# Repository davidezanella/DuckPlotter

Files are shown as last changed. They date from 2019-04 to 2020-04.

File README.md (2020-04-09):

# DuckPlotter

Arduino plotter made with a 3d printer capable to draw G-Code on paper.

Image of the Duckplotter

Video demo of the DuckPlotter in action:

Video demo of the DuckPlotter in action (https://www.youtube.com/watch?v=VcAsxya50rk)

## How to use DuckPlotter

### Configure the system

* Create the physical structure of the DuckPlotter
* Send code to Arduino
* Install all python requirements:

    go into `computer_code` folder and run

    `pip install -r requirements.txt`

### Generate the Gcode file from an image

#### First solution

* Download and install the program [`Image to gcode - DP`](https://github.com/davidezanella/image-to-gcode-DP) created ad hoc for the DuckPlotter.

#### Second solution

* Download and install the [Inkscape](https://inkscape.org) program and its [Laser Tool Plug-In](http://jtechphotonics.com/?page_id=2012)
* Open your image with Inkscape
* Convert the image to a Path image using the grey scale option
* Ungroup the layers of the image
* Choose the best layer and fix it removing or adding pixels

    If you need help doing these steps follow [this video](https://www.youtube.com/watch?v=U248SJcxRWA).

* Finally export Gcode from your image using the "Extensions" tab and selecting the option "Generate Gcode"

### Start the plotting process

* Execute the duckPlotter program:

    ```
    usage: duckPlotter.py [-h] [--continue PREV_FILE_NAME] file_name serial_port

    DuckPlotter pc program. Send g-code instructions to Arduino.

    positional arguments:
    file_name                       g-code file to plot
    serial_port                     serial port of Arduino

    optional arguments:
    -h, --help                      show this help message and exit
    --continue PREV_FILE_NAME       previous g-code file

    ```

    Example of usage:

    `python3 duckPlotter.py my-gcode-file.gcode /dev/ttyACM0`

    The `--continue` option allow to continue plotting without resetting to the initial position. It needs to know the previous file.

* You can split a gcode file in more files in order to avoid overheatings:

    `python gcodeSplitter.py gcode-file [max-lines]`

    The `max-lines` option allow to split the gcode file every `max-lines` lines. (Default value: 2500)

    All required gcode files will be generated. They have to be executed in order, with the `--continue` option specifying the previous g-code file.

## Used libraries
* [ArduinoJson](https://arduinojson.org)
* [Servo by Michael Margolis, Arduino](https://platformio.org/lib/show/883/Servo)

## Used hardware
* Arduino Mega 2560
* RAMPS 1.4 (RepRap Arduino MEGA Pololu Shield)

## Authors
- [Davide Dorigoni](https://github.com/DavDori)
- [Davide Zanella](https://github.com/davidezanella)

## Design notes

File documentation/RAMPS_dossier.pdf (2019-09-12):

# RAMPS 1.4 Assembly Guide

# 3D Printer Czar

## Version 1

## Table of Content

## Getting to know RAMPS 1.4 ---------------------------------------------------3

## Insert jumpers to RAMPS 1.4---------------------------------------------------4

## Connect the boards---------------------------------------------------------------4

## Crimp Connectors-----------------------------------------------------------------5

## Connect the Power Supply------------------------------------------------------6

## Connect the Rest------------------------------------------------------------------7

## Getting to know RAMPS 1.4

RAMPS 1.4 is probably the most widely used electronics for RepRap machines as of March 2014. It consists of a RAMPS 1.4 shield, an Arduino Mega 2560 board (or a clone), and a max of five Pololu Stepper drivers. It can control up to 5 stepper motors with 1/16 stepping precision and interface with a hotend, a heatbed, a fan (or a second hotend), a LCD controller, a 12V (or 24V with appropriate modification) power supply, up to three thermistors, and up to six end stoppers.

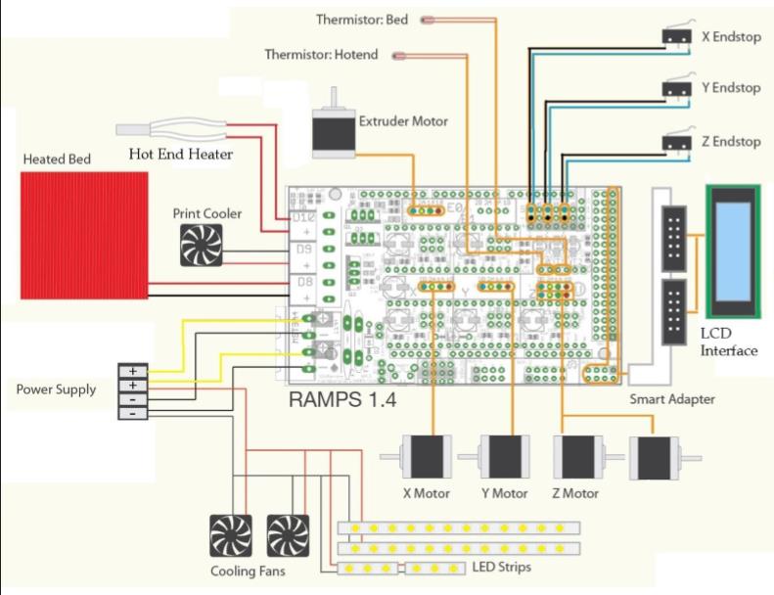
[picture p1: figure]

RAMPS 1.4 Schematic, taken from www.makerfarm.com

## 1. Insert jumpers to RAMPS 1.4

The jumpers (in the plastic bag below) control the precision of the motor movement. To have the most precise stepping (1/16 micro stepping), insert three jumpers to each of the areas outlined below：

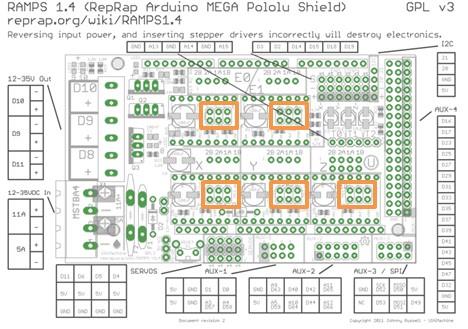
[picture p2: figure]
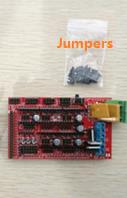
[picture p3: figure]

Install all jumpers to the orange area to ensure the most precise stepping

If you would like to learn about other modes of stepping (full stepping, half stepping, 1/8 stepping, etc.), please refer to this article: http://www.nmbtc.com/step-motors/engineering/full-half-and-microstepping.html. (http://www.nmbtc.com/step-motors/engineering/full-half-and-microstepping.html) These modes are not suitable for 3D printer motion control, but could be useful for other projects.

## 2. Connect the Boards

Stack the RAMPS 1.4 shield on top of the Arduino Mega 2560 board. Make sure the orientation is correct as shown above. The Mega 2560 board’s USB side is directly under RAMPS 1.4 shied’s “D8 D9 D10” area.

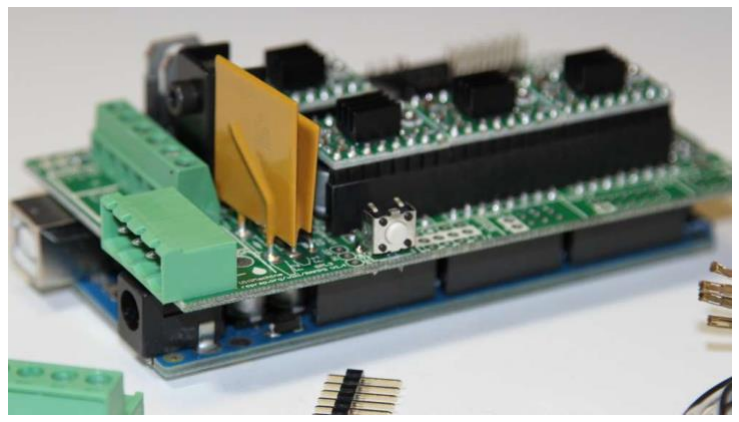
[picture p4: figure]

Stack up the RAMPS 1.4 shield on top of Mega 2560 Board

Next stack the Pololu steppers on top of the RAMPS 1.4 shield. MAKE SURE THE ORIENTATION IS CORRECT AS SHOWN BELOW! The potential meter (outlined in red on the right picture below) should be facing away from the “D10 D9 D8” side on the RAMPS 1.4 shield. We have heard numerous cases where these steppers got fried because of incorrect orientation. Install the heat sinks on the Pololu steppers, and make sure the heat sink are not touching multiple components on the Pololu stepper (the clearance could be small, but it is there!)

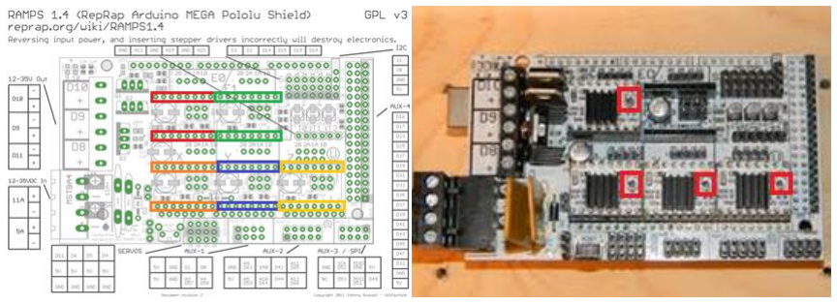
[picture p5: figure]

Install the Five Pololu steppers in the boxed pins shown on the left picture. Make sure the Potentiometer on the Pololu stepper is away from the side labeled “D10 D9 D8”.

## 3. Crimp Connectors

Motors, hotend thermistor, and the heatbed thermistor have bare wires. You need to crimp the Dupont connector pins and attach the connector shells. It might be easy to use a crimping tool (the best place to find one is Ebay or Radio shack), but needle nose pliers also work. This Instructables article gives a detailed step by step guide to crimping connectors: http://www.instructables.com/id/How-to-Make-A-Quality-Crimped-Joint/

When crimping the motor connectors, follow the Black-Green-Blue-Red order. If you find the motor spinning the opposite direction later, simply disconnect and flip the connector (make sure you do this while the power is off, otherwise you risk frying the Pololu boards).

The thermistor connector does not have a particular orientation.

## 4. Connect the Power Supply

If you are in a region with 110V outlet, first open the case and and switch to the 110V mode.

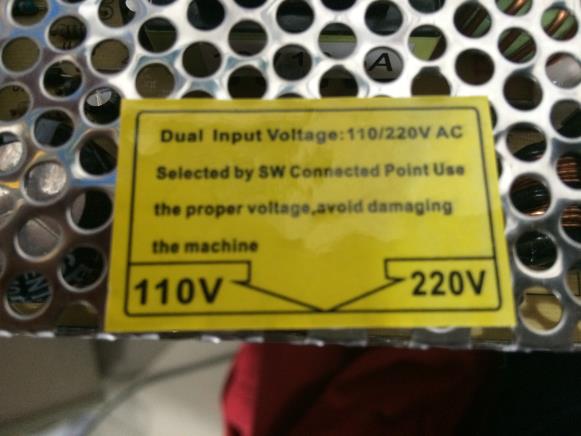
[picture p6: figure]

Switch to the correct voltage before use.

Cut the end of the power plug (not included in the kit) to reveal the three wires: Brown, Blue, Green (you might get a different set of colors depending on your power plug. If that’s the case, use a multi-meter to determine the L, N, and G nodes). Strip these wires and connect them to the power supply unit’s L, N, G nodes respectively. Untighten the screws and slide the stripped wires underneath, and retighten them. Give the wires a gentle pull to make sure they are tightened properly.

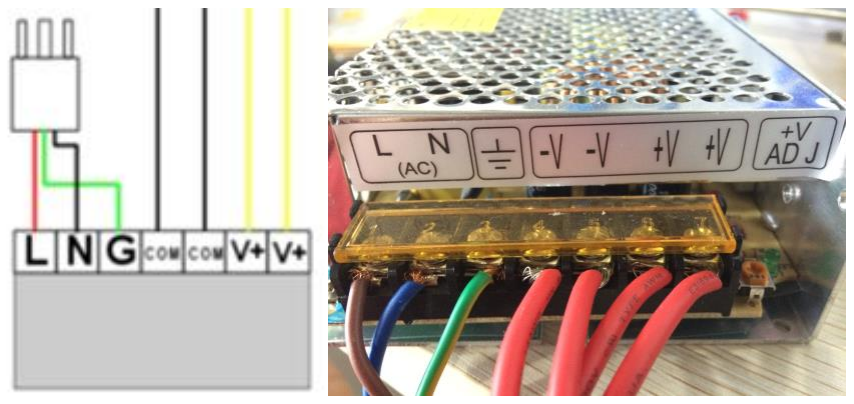
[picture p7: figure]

Get four spare wires and connect them on the two Com(V-) and the two V+ nodes. Connect the other ends to the RAMPS 1.4 shield’s power input nodes:

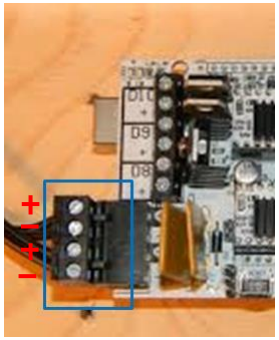
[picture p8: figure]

The first one on the bottom is COM(-V), then V+, then Com, then V+ again as shown above.

5. Connect Motors, Thermistors, Hotend, Heatbed, and Fan.

If you find motors spinning in a different direction, please switch the power off and simply flip the motor connector. There are two connectors in parallel for Z axis, since most RepRap machines use two motors to move in Z direction.

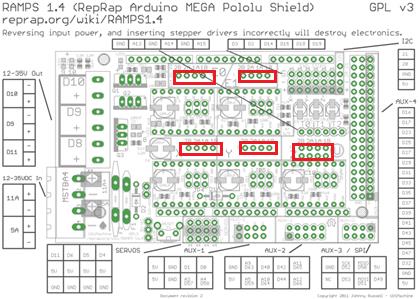
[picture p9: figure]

Top left: extruder 1. Top right: extruder 2. Bottom left: X-motor. Bottom middle: Y-motor. Bottom right: Z-motors.

There are three thermistor connector pins. From left to right: extruder 1, heatbed, and extruder 2. These are not polarity-sensitive.

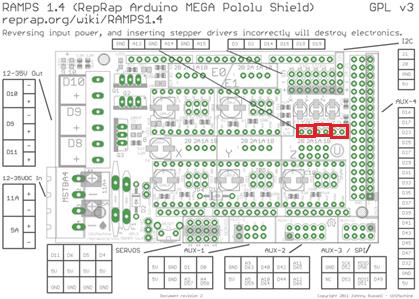
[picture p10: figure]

From left to right: Extruder 1 thermistor, heat bed thermistor, and extruder 2 thermistor

Plug in extruder 1 heater to D10, heatbed heater to D8, and fan(or a second extruder) to D9. Only the fan is polarity-sensitive.

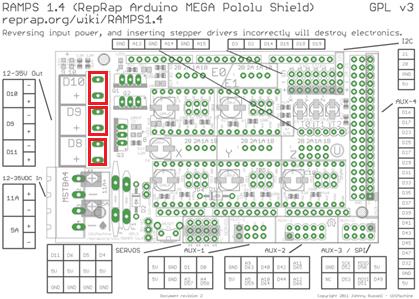
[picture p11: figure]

From top to bottom: extruder heater 1, fan, and heatbed heater.

The mechanical endstoppers are polarity sensitive. Solder wires to the “COM” and “NC” leads. Connect these two leads to the top two rows in the endstopper area outline below, with COM on the bottom and NC on top. From left to right, each column corresponds to xmin, xmax, ymin,ymax, zmin, and zmax. If you are using optical end stopper, then you will need all three pins. You only need to connect all max or all min end stoppers. The other limit will be specified in your firmware.

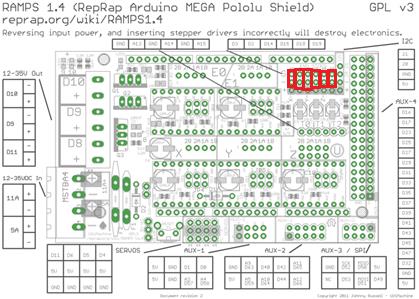
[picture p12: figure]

From left to right: X-min, X-max, Y-min, Y-max, Z-min, and Z-max.

Finally, connect the LCD smart controller to the specified pins.

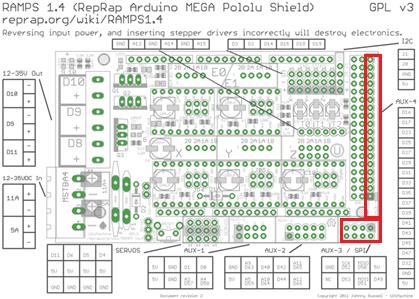
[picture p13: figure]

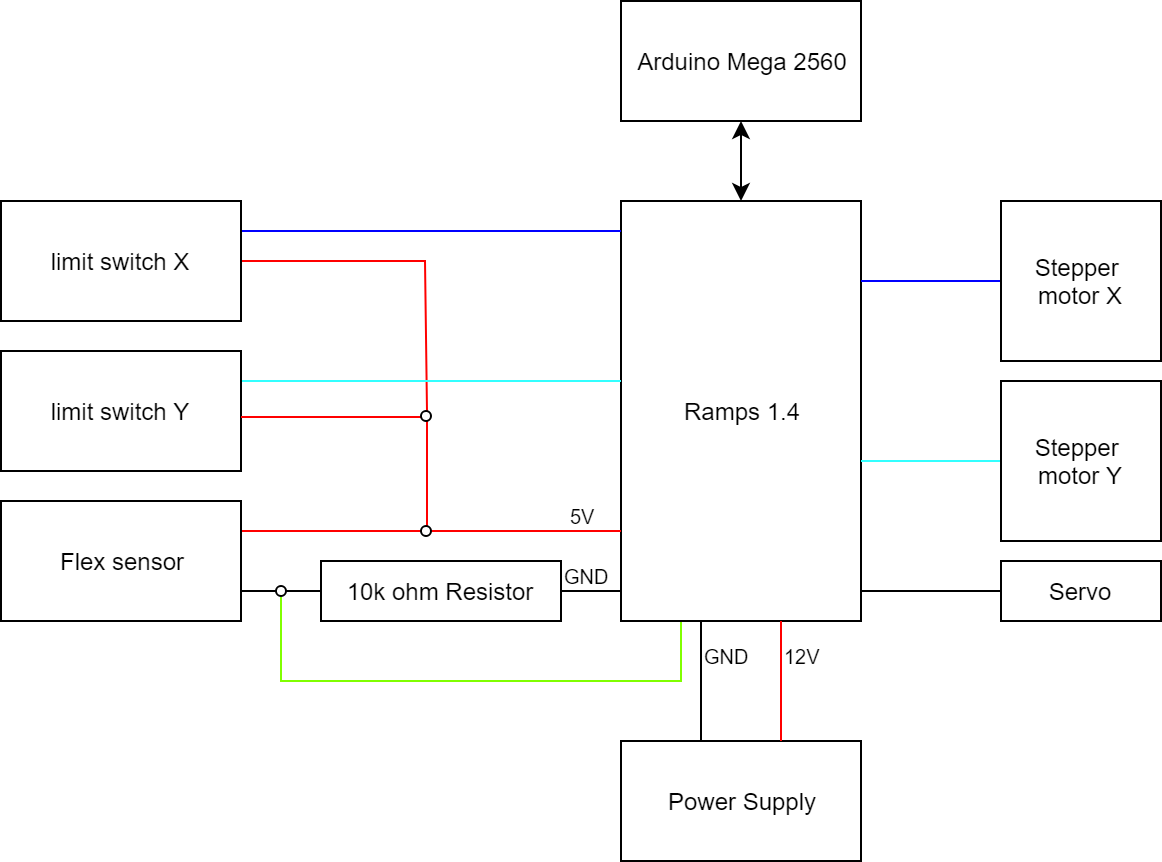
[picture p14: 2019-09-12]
documentation/duckplotter_scheme.png

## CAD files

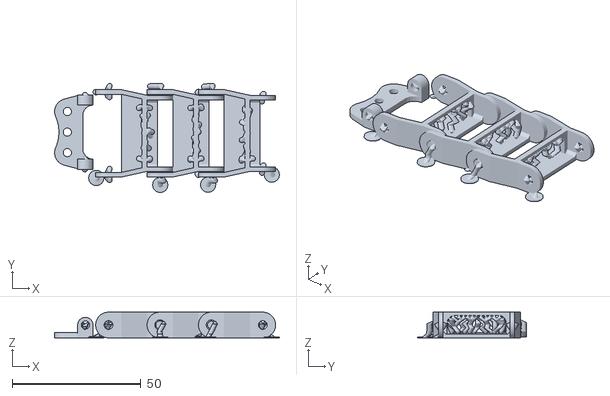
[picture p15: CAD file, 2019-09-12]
3d_models/chain/chain_end_2.stl
87.5 x 42.5 x 10.0

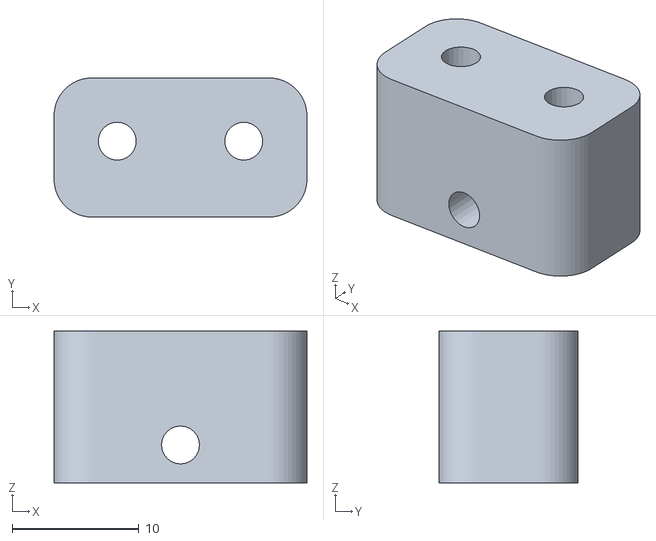
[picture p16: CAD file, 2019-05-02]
3d_models/duck_limitSwitchTop.stl
20.0 x 11.0 x 12.0

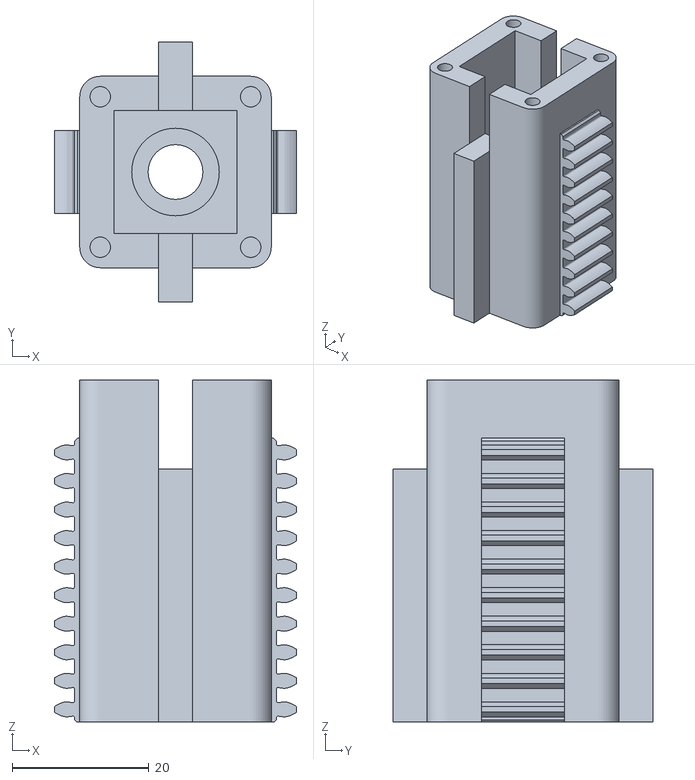
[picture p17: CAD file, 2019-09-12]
3d_models/penHolder/penHolderMk4_chamber.stl
35.4 x 38.0 x 50.0

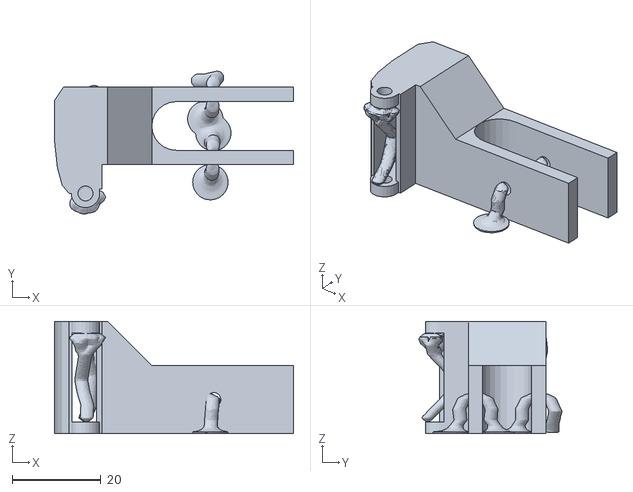
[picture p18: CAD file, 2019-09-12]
3d_models/chain/chain_end_1.stl
54.0 x 32.3 x 25.4

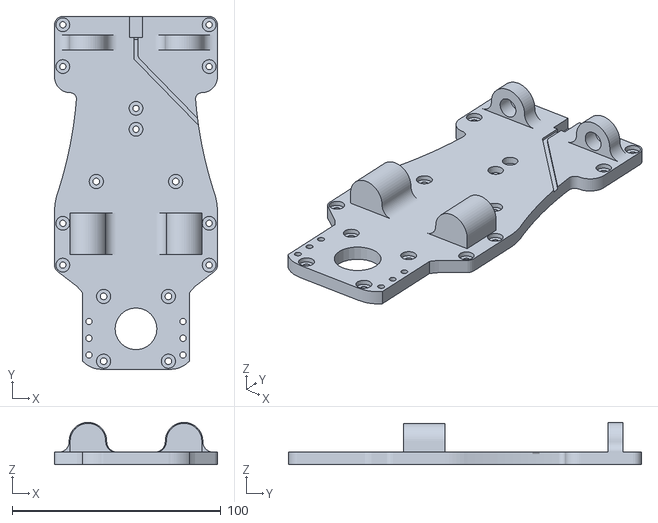
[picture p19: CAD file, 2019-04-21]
3d_models/duck_plotter_base.stl
78.0 x 169.0 x 20.2

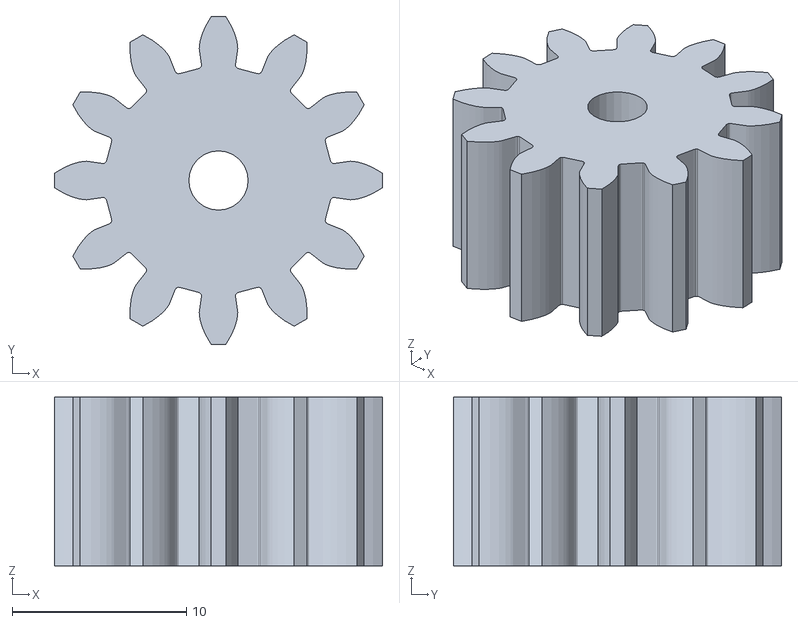
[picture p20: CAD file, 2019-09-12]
3d_models/penHolder/penHolderMk4_freeGear.stl
18.8 x 18.8 x 9.68

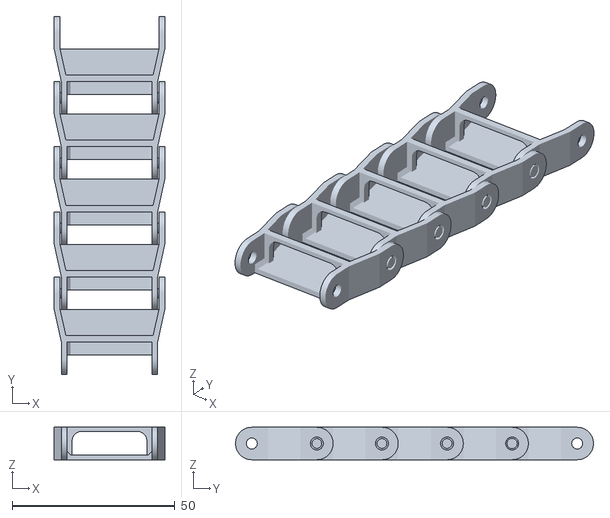
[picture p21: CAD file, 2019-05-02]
3d_models/chain/duck_chain_v03.stl
34.0 x 110.0 x 10.0

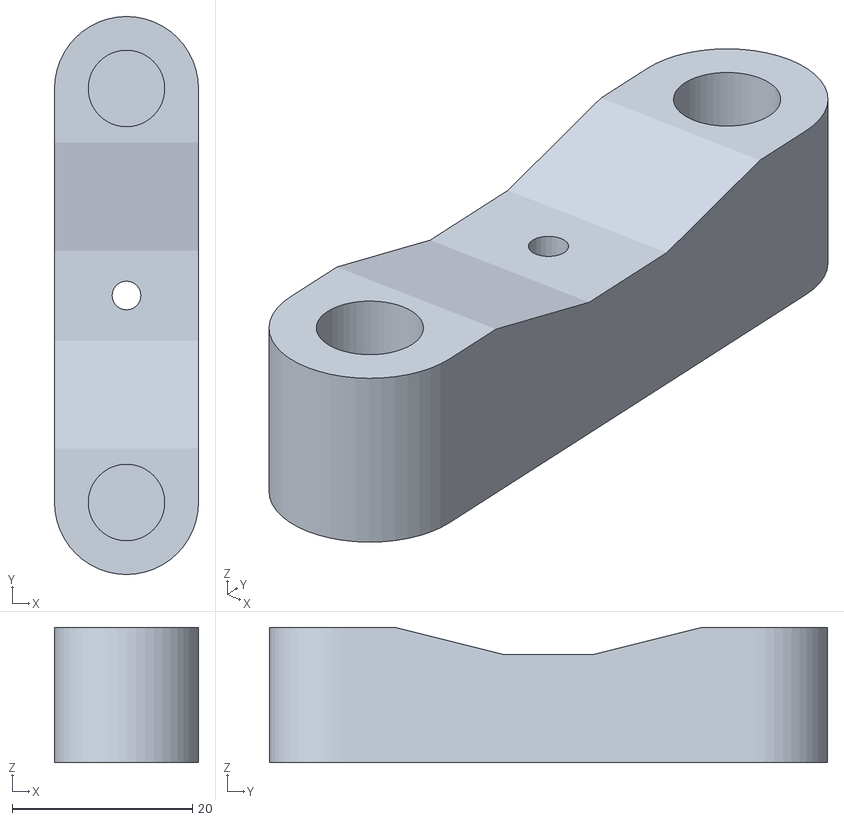
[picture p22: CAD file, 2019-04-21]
3d_models/duck_plotter_end.stl
16.0 x 62.0 x 15.0

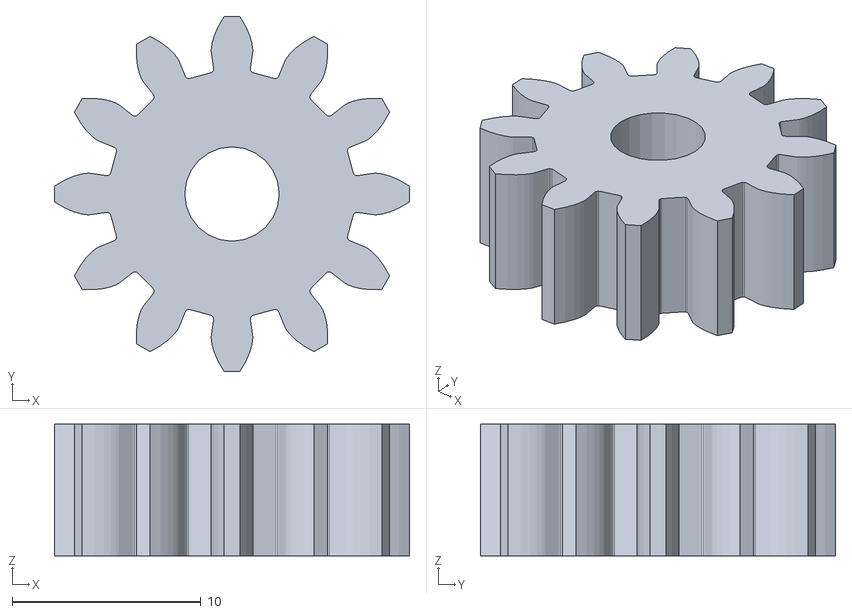
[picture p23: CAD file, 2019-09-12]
3d_models/penHolder/penHolderMk4_MotGear.stl
18.8 x 18.8 x 6.97

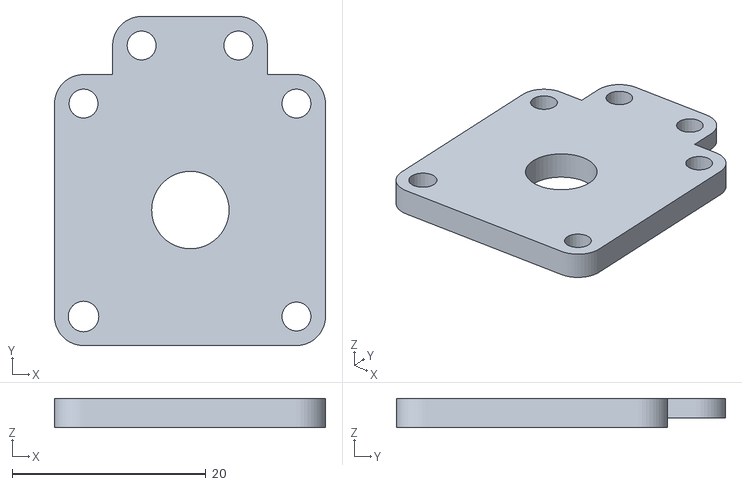
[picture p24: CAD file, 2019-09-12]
3d_models/penHolder/penHolderMk4_top.stl
28.0 x 34.0 x 3.00

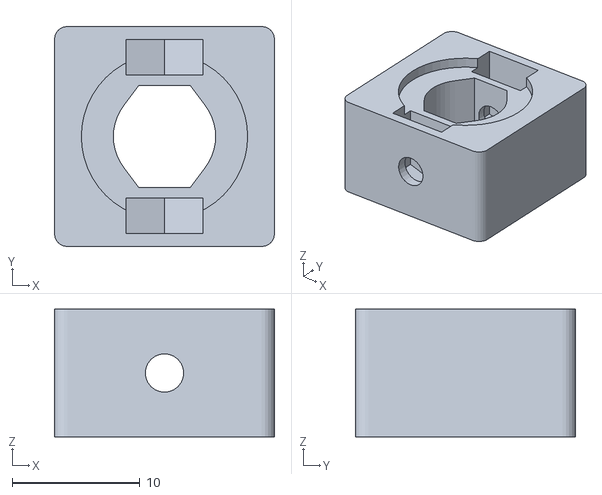
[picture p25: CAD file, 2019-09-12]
3d_models/penHolder/penHolderMk4_penBlock.stl
17.2 x 17.2 x 10.0

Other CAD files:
3d_models/penHolder/penHolderMk4.skp

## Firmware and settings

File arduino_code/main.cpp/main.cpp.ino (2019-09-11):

#include <ArduinoJson.h>
#include "DuckPlotter.h"

#define BAUD 9600

Position last;
DuckPlotter plotter = DuckPlotter();

void setup() {
  Serial.begin(BAUD);
  plotter.init();

  last.x = 0;
  last.y = 0;
}

void start() {
  String input;
  StaticJsonDocument<200> doc;
  if (Serial.available() > 0) {
    input = Serial.readStringUntil('\n');

    DeserializationError error = deserializeJson(doc, input);

    if (error) {
      Serial.print(F("deserializeJson() failed: "));
      Serial.println(error.c_str());
      return;
    }

    String type = doc["type"];

    if (type == "reset") {
      plotter.reset();
    }
    else if (type == "sync") {
      last.x = doc["x"];
      last.y = doc["y"];
    }
    else if (type == "movement") {
      String moveType = doc["move_type"];
      Position to;
      to.x = doc["toX"];
      to.y = doc["toY"];
      bool clockwise = doc["clockwise"];
      if (moveType == "linear") {
        last = plotter.moveLinear(last, to);
      }
      else if (moveType == "arc") {
        if (doc.containsKey("offsetX")) {
          Position offset;
          offset.x = doc["offsetX"];
          offset.y = doc["offsetY"];
          last = plotter.moveArc(last, to, offset, clockwise);
        }
        else {
          double radius = doc["radius"];
          last = plotter.moveArc(last, to, radius, clockwise);
        }
      }
    }
    else if (type == "pen") {
      bool down = doc["down"];
      plotter.movePen(down);
    }

    Serial.println("Done");
  }
}

void loop()
{
  start();
}

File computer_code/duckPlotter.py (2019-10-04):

#!/usr/bin/python3
import serial
import json
import sys
import time
from gCodeParser import parse, findLastPosition
from tqdm import tqdm
import argparse

baudRate = 9600


def sendData(ser, obj):
    data = json.dumps(obj) + "\n"
    for d in data:
        ser.write(str(d).encode())

    tqdm.write("Sent: " + data)


def readData(ser):
    return str(ser.readline())


def main():
    parser = argparse.ArgumentParser(description='DuckPlotter pc program. Send g-code instructions to Arduino.')
    
    parser.add_argument('file_name', help='g-code file to plot')
    parser.add_argument('serial_port', help='serial port of Arduino')
    parser.add_argument('--continue', action='store', dest='prev_file_name', help='previous g-code file')
    
    args = parser.parse_args()

    gcode_file = open(args.file_name, 'r')
    gcode = gcode_file.read()
    data = parse(gcode)

    ser = serial.Serial(args.serial_port, baudRate, timeout=None)

    time.sleep(2) # wait for Arduino

    reset = [{
        'type': 'reset'
    }]

    sync = [{
        'type': 'sync',
        'x': 0,
        'y': 0
    }]

    if args.prev_file_name is None:
        data = reset + data
    else:
        prev_file = open(args.prev_file_name, 'r')
        lines = prev_file.readlines()
        x, y = findLastPosition(lines)
        sync[0]['x'], sync[0]['y'] = x, y
        data = sync + data
        print("Resuming from: x = " + str(x) + ", y = " + str(y))

    for instr in tqdm(data):
        sendData(ser, instr)
        time.sleep(1)
        result = readData(ser)
        tqdm.write("Read: " + result)

        #print debug code from the Arduino
        while "Done" not in result:
            tqdm.write("\t" + str(result))
            result = readData(ser)

    ser.close()


if __name__ == "__main__":
    main()

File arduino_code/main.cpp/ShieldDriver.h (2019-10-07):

#ifndef _SHIELDRIVER_h
#define _SHIELDDRIVER_h

#include "ShieldStepper.h"
#include <Arduino.h>

#define X_STEP_PIN         54
#define X_DIR_PIN          55
#define X_ENABLE_PIN       38
#define X_MIN_PIN           3
#define X_MAX_PIN           2

#define Y_STEP_PIN         60
#define Y_DIR_PIN          61
#define Y_ENABLE_PIN       56
#define Y_MIN_PIN          14
#define Y_MAX_PIN          15

#define Z_STEP_PIN         46
#define Z_DIR_PIN          48
#define Z_ENABLE_PIN       62
#define Z_MIN_PIN          18
#define Z_MAX_PIN          19

#define E_STEP_PIN         26
#define E_DIR_PIN          28
#define E_ENABLE_PIN       24

#define Q_STEP_PIN         36
#define Q_DIR_PIN          34
#define Q_ENABLE_PIN       30

#define SDPOWER            -1
#define SDSS               53
#define LED_PIN            13

#define FAN_PIN            9

#define PS_ON_PIN          12
#define KILL_PIN           -1

#define HEATER_0_PIN       10
#define HEATER_1_PIN       8
#define TEMP_0_PIN          13   // ANALOG NUMBERING
#define TEMP_1_PIN          14   // ANALOG NUMBERING


//define all the stop button
#define X_STOP_PIN 3
#define X_INVERT_DIR 0

#define Y_STOP_PIN 14
#define Y_INVERT_DIR 1

#define Z_STOP_PIN 18
#define Z_INVERT_DIR 0

#define E_STOP_PIN 1 //random
#define E_INVERT_DIR 0

#define Q_STOP_PIN 1 //random
#define Q_INVERT_DIR 0


class ShieldDriver
{
  public:

    //Constructor
    ShieldDriver();

    //Reset motor positions
    void reset();

    //declare all the stepper motors
    ShieldStepper motorX = ShieldStepper(X_STEP_PIN, X_DIR_PIN, X_ENABLE_PIN, X_STOP_PIN, X_INVERT_DIR);
    ShieldStepper motorY = ShieldStepper(Y_STEP_PIN, Y_DIR_PIN, Y_ENABLE_PIN, Y_STOP_PIN, Y_INVERT_DIR);
    //in our project only motorX and motorY have been used, uncomment to enable:
    //ShieldStepper motorZ = ShieldStepper(Z_STEP_PIN, Z_DIR_PIN, Z_ENABLE_PIN, Z_STOP_PIN, Z_INVERT_DIR);
    //ShieldStepper motorE = ShieldStepper(E_STEP_PIN, E_DIR_PIN, E_ENABLE_PIN, E_STOP_PIN, E_INVERT_DIR);
    //ShieldStepper motorQ = ShieldStepper(Q_STEP_PIN, Q_DIR_PIN, Q_ENABLE_PIN, Q_STOP_PIN, Q_INVERT_DIR);

  private:

};

#endif

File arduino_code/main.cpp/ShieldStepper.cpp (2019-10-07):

#include "ShieldStepper.h"

/**
   Constructor
*/
ShieldStepper::ShieldStepper(int _stepPin, int _dirPin, int _enablePin, int _stopPin, int _invertDir)
{
  stepPin = _stepPin;
  dirPin = _dirPin;
  enablePin = _enablePin;
  stopPin = _stopPin;
  invertDir = _invertDir;

  pinMode(stepPin, OUTPUT);
  pinMode(dirPin, OUTPUT);
  pinMode(enablePin, OUTPUT);

  digitalWrite(enablePin, LOW);

  pinMode(stopPin, INPUT_PULLUP);
}

/**
   Set the direction of the stepper motor
*/
void ShieldStepper::setDirection(short _dir)
{
  if (invertDir == 0) //invert positions
  {
    _dir = !_dir;
  }

  digitalWrite(dirPin, _dir);
}

/**
   Make one step
*/
void ShieldStepper::step()
{
  //make one step setting high and low the state
  digitalWrite(stepPin, HIGH);
  delayMicroseconds(step_time); //delay between each step
  digitalWrite(stepPin, LOW);
}

/**
   Make a number of steps.
   If the number is negative the direction will be inverted
*/
void ShieldStepper::makeSteps(int _nSteps)
{
  int dir = (_nSteps > 0) ? 1 : 0;
  setDirection(dir);

  for (int i = 0; i < abs(_nSteps); i++)
  {
    //make one step per time
    step();
  }
}

/**
   Change the delay between each step
*/

void ShieldStepper::setTime(unsigned long _step_time)
{
  step_time = _step_time;
}

/**
   Reset the position of the motor
*/
void ShieldStepper::reset()
{
  setDirection(0);
  while (!limitReached())
  {
    step();
  }
}

/**
   Check if the motor has reached its limit
*/
bool ShieldStepper::limitReached()
{
  return digitalRead(stopPin);
}

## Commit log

2019-04-14 Add arduino basic json parser functionality
2019-04-20 added printable 3d model of the plotter base.
    [duck_printer.skp]
2019-04-21 Add 3D model of Plotter base and second axis block plus Arduino code for steppers movement
    [duck_plotter_base.stl, duck_plotter_end.stl, duck_printer.skp]
2019-04-22 Add chain to keep together wires
    [duck_chain.stl]
2019-04-23 Add functions to find the movement coordinates from arduino
2019-04-24 New version of the Chain, stronger and larger.
2019-05-02 new version of chain 3d model
    [duck_chain.stl, duck_chain_v03.stl, duck_finecorsa_asse1.stl]
2019-07-15 Add files via upload
    homeX and homeY functions, swtich, and stepper control
2019-08-08 Improved gcode parsing and Arduino communication
2019-08-08 Add custom stepper motors library
2019-08-09 Add pen motor and cleaned up code
2019-08-09 Fix servo init
2019-08-26 Fixed near function for arc movement
    [DuckPlotter.cpp, DuckPlotter.h]
2019-08-26 Add option to continue without resetting
    [duckPlotter.py]
2019-08-28 Add feature to send actual position to Arduino at start
2019-09-12 add new models, including penHolder and more documentation
    [chain_end_1.stl, chain_end_2.stl, duck_chain_v03.stl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]
2019-10-07 add new delay value and unused stepper motors have been removed
